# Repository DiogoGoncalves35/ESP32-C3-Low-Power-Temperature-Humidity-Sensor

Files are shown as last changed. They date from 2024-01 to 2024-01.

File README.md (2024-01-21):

# ESP32-C3-Low-Power-Temperature-Humidity-Sensor

  

This board is designed arround SHT31 sensor and ESP32-C3 microcontroller. It's a low power board, arround 6 µA during deep sleep, it's super efficient during communication, makes it perfect to be powered with a Li-Ion battery. The next image shows version 2.0.

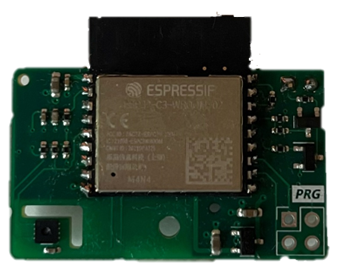
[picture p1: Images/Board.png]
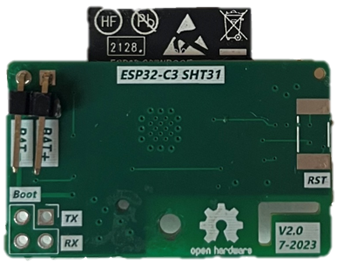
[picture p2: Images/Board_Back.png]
 

Two versions were designed, the first was a experimental board and the second the final one. The second version solved the problems found on the first and also added a circuit to control the voltage divider, this helped reduce the deep sleep current by 9 µA.

| | V1.0 | V2.0 | 
| --- | ---  | ---  |
| Current Deep Sleep (µA) | 13.33 | 6.03 | 

The microcontroller wakes every 5 minutes to do the measurement and send the data. With this value, the device can last up to 1800 days with a 550 mAh Li-Ion battery. This is a estimated  value because it's not easy to calculate the exact one, the system doesn't consume the exact ammount every cycle and the battery datasheet doesn't state the BMS drawn current. 

------------

### Communication Protocol 

In order to choose the most efficient protocol, three tests were executed between BLE, ESP-NOW and MQTT. The first test was about message delivering, each test corresponds to sending messages every 5 minutes for 24 hours (288 messages per day). 

The values on the table show the average result for 10 tests.

| | ESP-NOW | MQTT | BLE (NimBLE)  |
| ---  | ---  | ---  | ---  |
| Average (%) | 100.0 | 97.4 | 99.8 |

ESP-NOW was the only protocol to delivery every message. 

MQTT couldn't get 100% in any test, it lost about 3 to 8 messages per test, this loss could be related to the library used not support QoS 0. In case the broker didn't receive the packet 750 ms after the first send, another one was published and if after 750 ms the broker still didn't received, the board entered deep sleep. Wi-Fi connection with fixed IP.

BLE in 6 tests delivered every message and in the others lost about 2 to 4 messages, for the test NimBLE library was used, the default BLE library has many problems related to memory.

The last test is about the average current and time during execution. The values on the table show the average result for 10 measurements. The time corresponds to the moment the ESP wakes from deep sleep and goes into deep sleep.

| | ESP-NOW | MQTT | BLE (NimBLE)  |
| ---  | ---  | ---  | ---  |
| Current (mA)  | 28.76 | 69.65 | 80.57 |
| Time (ms) | 85.31 | 906.26 | 737.57 |

ESP-NOW is by far the most efficient protocol, the way it's built allows communication to be direct and fast. Since it only uses the antenna to send the message, it's possible to achive low current during execution.

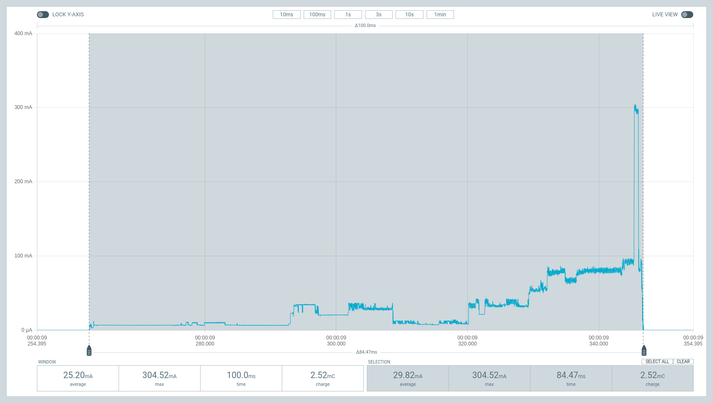
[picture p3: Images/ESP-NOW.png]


MQTT needs about 300-400 ms to connect to Wi-Fi and MQTT server, without fixed IP, connection time increases in 2 to 3 seconds. Average current increases compared to ESP-NOW because the antenna is used several times.

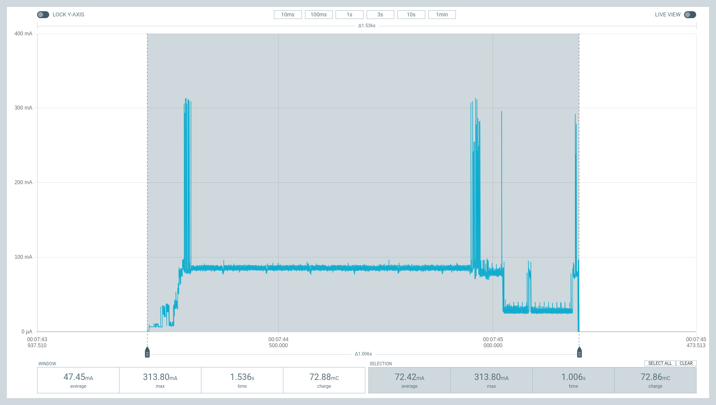
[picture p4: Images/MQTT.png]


BLE uses the antenna quite often because needs to adverstise the device, services and then transmit data to the other device. Eventhought it uses lower current, the average current is higher compared to MQTT.

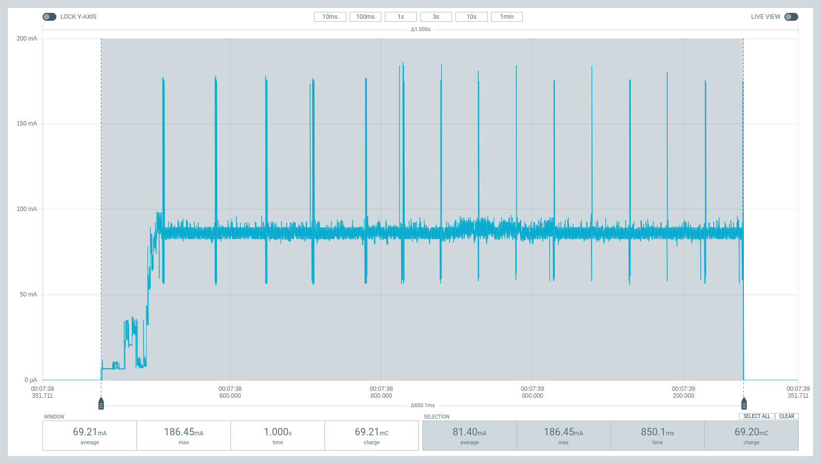
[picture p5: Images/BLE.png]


| | ESP-NOW | MQTT | BLE (NimBLE)  |
| --- | ---  | ---  | ---  |
| Difference (%) | --- | 96.10 | 95.90 |

ESP-NOW is 96.10% more efficient then MQTT and 95.90% then BLE.

After the results of both tests, ESP-NOW protocol was chose.

---

### Code 

The microcontroller saves the last reading in the RTC memory, by doing this it's possible to compare the values just measured to the ones stored in the memory. This allows the system to not send the message in case the measurements are the same and increases battery life.

```arduino
//Variables to store last measurement
RTC_DATA_ATTR double    RTC_Temperature = 0;
RTC_DATA_ATTR byte      RTC_Humidity    = 0;

// Block code after measurement
if(Data.Temperature == RTC_Temperature && Data.Humidity == RTC_Humidity)
{
    // Start deep sleep
    esp_deep_sleep_start();
}
else
{
    // Store values 
    RTC_Temperature = Data.Temperature;
    RTC_Humidity    = Data.Humidity;
}
```

The board responsible for receiving data needs to have the same data structure.

```arduino
// ESP-NOW data structure   
typedef struct struct_message 
{
  byte   ID = X;               // Board identifier
  float  Temperature;          // Temperature variable
  byte   Humidity;             // Humidity variable
  byte   Battery_Percentage;   // Battery percentage variable
} struct_message;

struct_message Data;
```

The frequency that the code runs impacts current and time of execution. The code was divide in two phases, the first is from the moment the board wakes from deep sleep to the moment it starts the ESP-NOW function, the second is from the start of ESP-NOW function to the moment it enters in deep sleep. After some measurements done, the results showed 40-160 MHz was the most efficient combination. In case the microcontroller sends every message, running with fixed 160 MHz is more efficient.

---

### Schematic 

The [schematic](/Hardware/PCB/Schematic.pdf) is arround ESP32-C3 microcontroller and SHT31 sensor. The P-Channel Mosfet BSS84 and the N-Channel Transistor S8050 control the voltage for the voltage divider. The board is designed to be powered with a Li-Ion battery that includes a BMS.

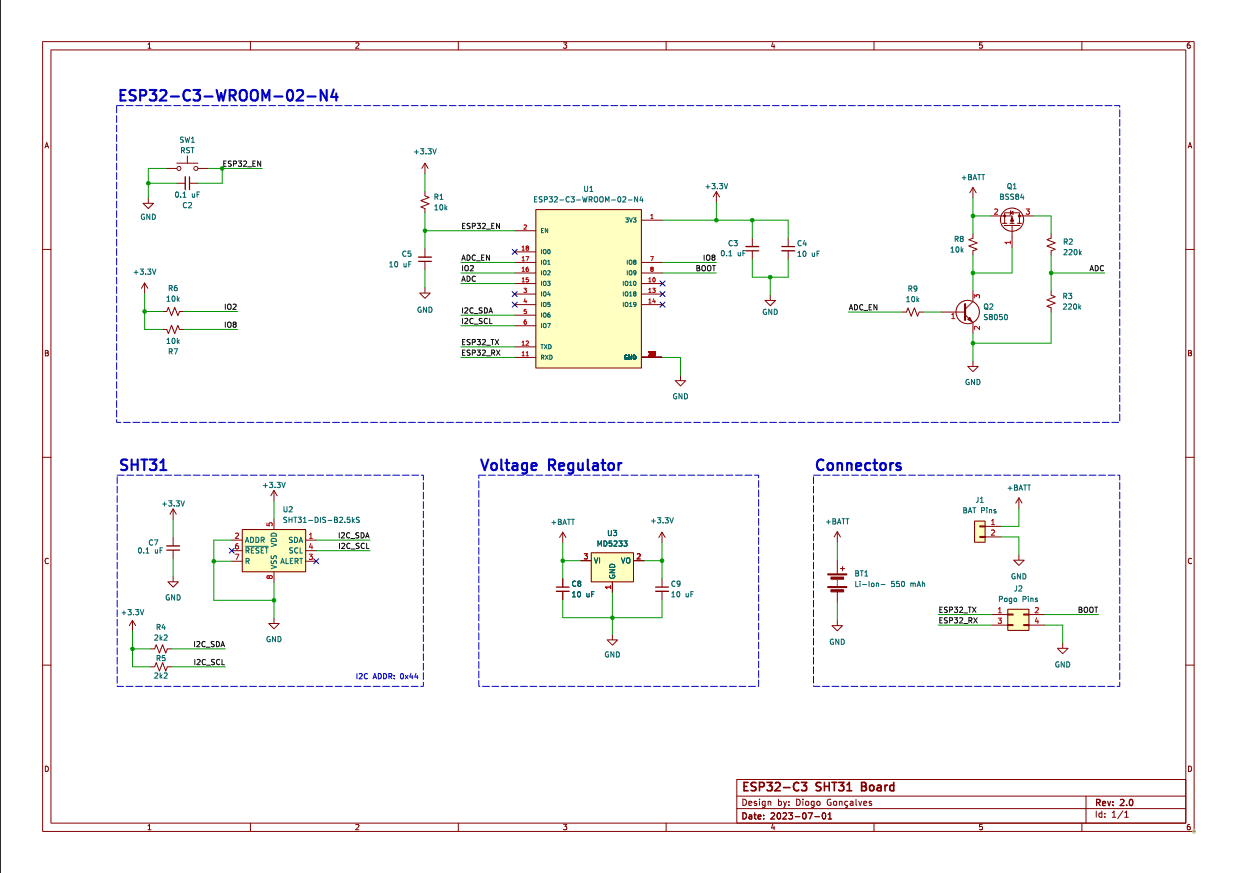
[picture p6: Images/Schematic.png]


------------

### PCB

[This](Hardware/PCB/) 1.6mm board contains 4 layers with the stackup Signal+Power/GND/GND/Signal+Power. GND area was removed closer to the sensor in order to not affect readings. The pogo pin connector is for programming the microcontroller. The reset button is located on the back.

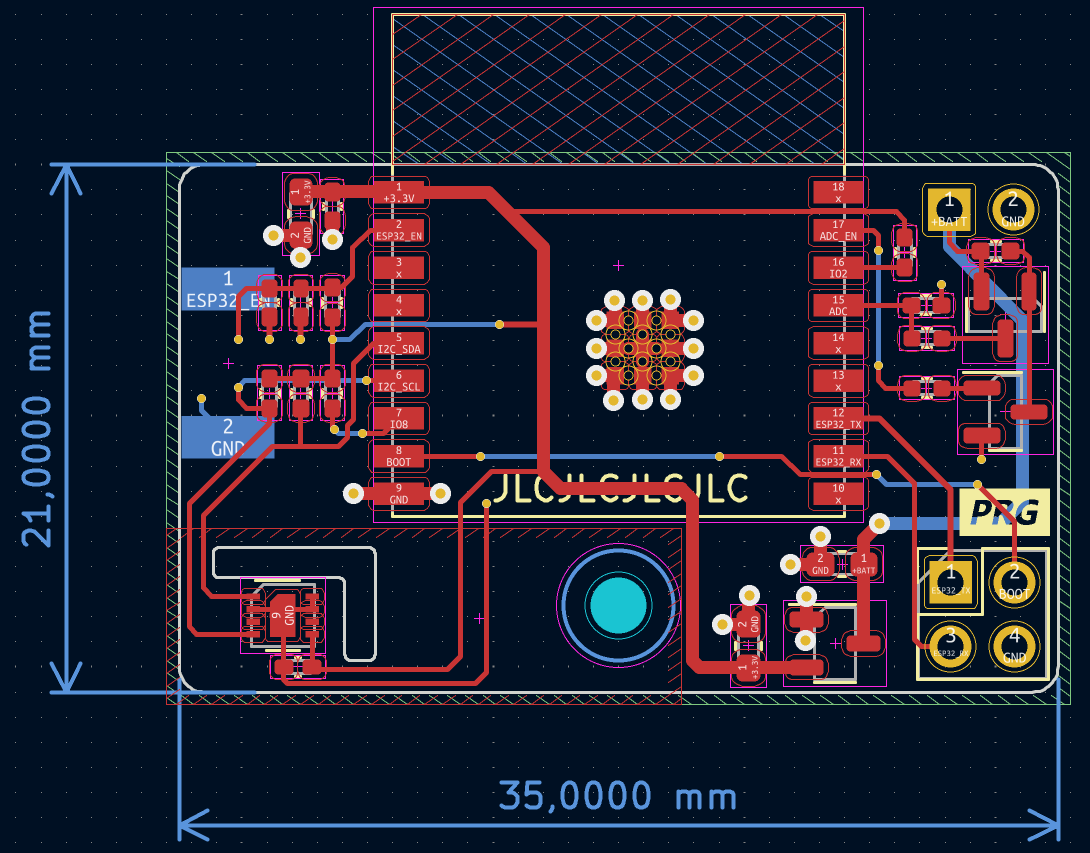
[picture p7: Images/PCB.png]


---

### Known issues

- None

------------

### To-Do

- TPL5110 Timer to control the microcontroller and reduce deep sleep current

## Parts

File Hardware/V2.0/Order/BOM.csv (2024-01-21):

Reference | Value | Footprint | LCSC | Qtd
BT1 | Li-Ion- 550 mAh | Connector_PinHeader_2.54mm:PinHeader_1x02_P2.54mm_Horizontal |  | 1
C2 | 0.1 uF | Capacitor_SMD:C_0402_1005Metric_Pad0.74x0.62mm_HandSolder | C1525 | 1
C3 | 0.1 uF | Capacitor_SMD:C_0402_1005Metric_Pad0.74x0.62mm_HandSolder | C1525 | 1
C4 | 10 uF | Capacitor_SMD:C_0603_1608Metric_Pad1.08x0.95mm_HandSolder | C19702 | 1
C5 | 10 uF | Capacitor_SMD:C_0402_1005Metric_Pad0.74x0.62mm_HandSolder | C15525 | 1
C7 | 0.1 uF | Capacitor_SMD:C_0402_1005Metric_Pad0.74x0.62mm_HandSolder | C1525 | 1
C8 | 10 uF | Capacitor_SMD:C_0603_1608Metric_Pad1.08x0.95mm_HandSolder | C19702 | 1
C9 | 10 uF | Capacitor_SMD:C_0603_1608Metric_Pad1.08x0.95mm_HandSolder | C19702 | 1
J1 | BAT Pins |  |  | 1
J2 | Pogo Pins | Connector_PinHeader_2.54mm:PinHeader_2x02_P2.54mm_Vertical |  | 1
Q1 | BSS84 | Package_TO_SOT_SMD:SOT-23 | C8492 | 1
Q2 | S8050 | Package_TO_SOT_SMD:SOT-23 | C2150 | 1
R1 | 10k | Resistor_SMD:R_0402_1005Metric_Pad0.72x0.64mm_HandSolder | C25744 | 1
R2 | 220k | Resistor_SMD:R_0402_1005Metric_Pad0.72x0.64mm_HandSolder | C25767 | 1
R3 | 220k | Resistor_SMD:R_0402_1005Metric_Pad0.72x0.64mm_HandSolder | C25767 | 1
R4 | 2k2 | Resistor_SMD:R_0402_1005Metric_Pad0.72x0.64mm_HandSolder | C25879 | 1
R5 | 2k2 | Resistor_SMD:R_0402_1005Metric_Pad0.72x0.64mm_HandSolder | C25879 | 1
R6 | 10k | Resistor_SMD:R_0402_1005Metric_Pad0.72x0.64mm_HandSolder | C25744 | 1
R7 | 10k | Resistor_SMD:R_0402_1005Metric_Pad0.72x0.64mm_HandSolder | C25744 | 1
R8 | 10k | Resistor_SMD:R_0402_1005Metric_Pad0.72x0.64mm_HandSolder | C25744 | 1
R9 | 10k | Resistor_SMD:R_0402_1005Metric_Pad0.72x0.64mm_HandSolder | C25744 | 1
SW1 | RST | SMD Switch:KEY-SMD_KSS-2G |  | 1
U1 | ESP32-C3-WROOM-02-N4 | ESP32-C3 WROOM-02:MODULE_ESP32-C3-WROOM-02-H4 | C2934560 | 1
U2 | SHT31-DIS-B2.5kS | Sensor_Humidity:Sensirion_DFN-8-1EP_2.5x2.5mm_P0.5mm_EP1.1x1.7mm | C80862 | 1
U3 | MD5233 | Package_TO_SOT_SMD:SOT-23-3 | C920353 | 1

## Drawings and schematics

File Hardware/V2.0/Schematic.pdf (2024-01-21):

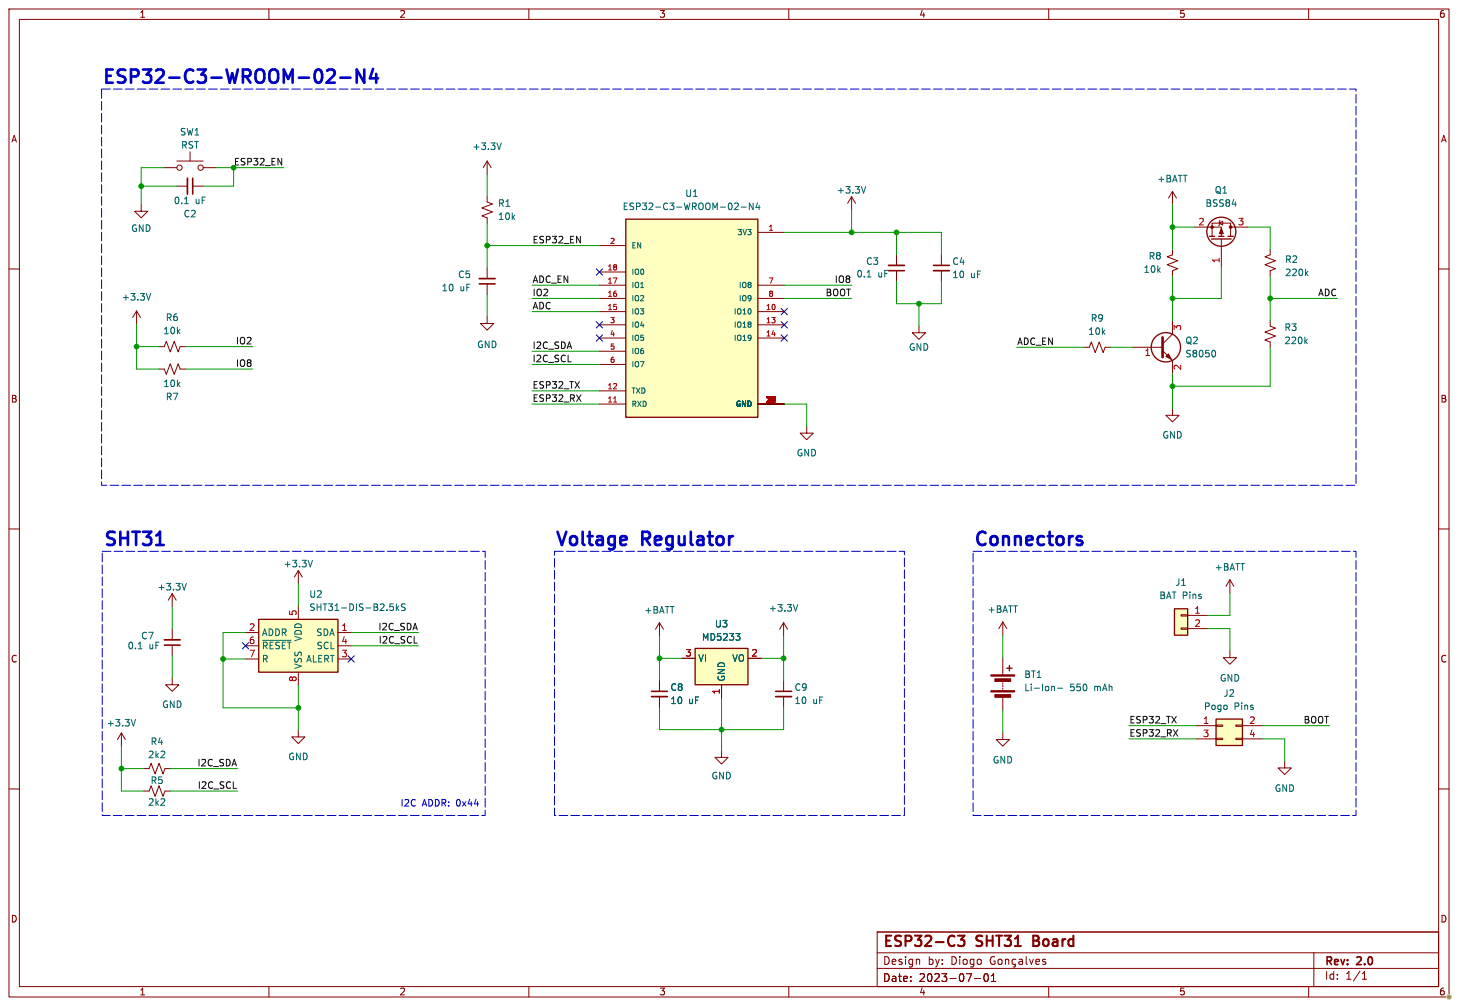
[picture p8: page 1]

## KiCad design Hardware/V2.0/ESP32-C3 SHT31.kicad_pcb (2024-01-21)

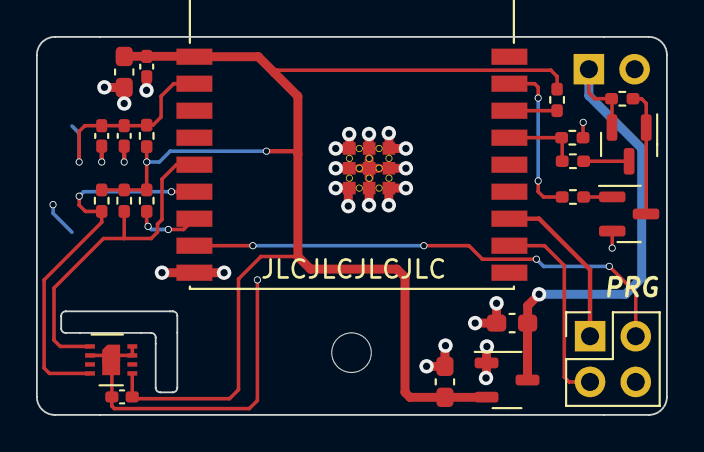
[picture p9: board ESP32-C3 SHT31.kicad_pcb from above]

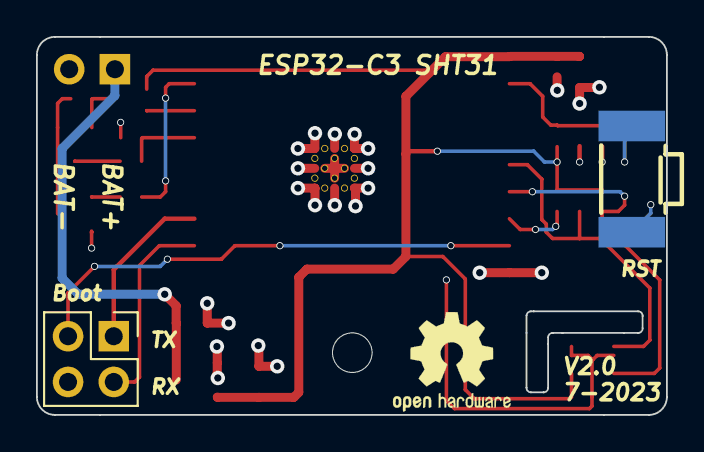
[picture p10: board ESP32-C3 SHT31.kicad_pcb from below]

Board: 4 copper layers, 35.0 x 21.0 mm, 24 parts (2 on the bottom side), 16 nets.

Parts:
BT1: Li-Ion- 550 mAh; PinHeader_1x02_P2.54mm_Horizontal
C2, C3, C7: 0.1 uF; C_0402_1005Metric_Pad0.74x0.62mm_HandSolder
C4, C8, C9: 10 uF; C_0603_1608Metric_Pad1.08x0.95mm_HandSolder
C5: 10 uF; C_0402_1005Metric_Pad0.74x0.62mm_HandSolder
J2: Pogo Pins; PinHeader_2x02_P2.54mm_Vertical
Q1: BSS84; SOT-23
Q2: S8050; SOT-23
R1, R6, R7, R8, R9: 10k; R_0402_1005Metric_Pad0.72x0.64mm_HandSolder
R2, R3: 220k; R_0402_1005Metric_Pad0.72x0.64mm_HandSolder
R4, R5: 2k2; R_0402_1005Metric_Pad0.72x0.64mm_HandSolder
SW1: RST; KEY-SMD_KSS-2G
U1: ESP32-C3-WROOM-02-N4; MODULE_ESP32-C3-WROOM-02-H4
U2: SHT31-DIS-B2.5kS; Sensirion_DFN-8-1EP_2.5x2.5mm_P0.5mm_EP1.1x1.7mm
U3: MD5233; SOT-23-3

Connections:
+3.3V: C3.2, C4.1, C7.2, C9.1, R1.1, R4.1, R5.1, R6.1, R7.1, U1.1 (3V3), U2.5 (VDD), U3.2 (VO)
+BATT: BT1.1 (+), C8.1, Q1.2 (S), R8.1, U3.3 (VI)
/ADC: R2.2, R3.2, U1.15 (IO3)
/ADC_EN: R9.1, U1.17 (IO1)
/BOOT: J2.2, U1.8 (IO9)
/ESP32_EN: C2.1, C5.2, R1.2, SW1.1, U1.2 (EN)
/ESP32_RX: J2.3, U1.11 (RXD)
/ESP32_TX: J2.1, U1.12 (TXD)
/I2C_SCL: R5.2, U1.6 (IO7), U2.4 (SCL)
/I2C_SDA: R4.2, U1.5 (IO6), U2.1 (SDA)
/IO2: R6.2, U1.16 (IO2)
/IO8: R7.2, U1.7 (IO8)
GND: BT1.2 (-), C2.2, C3.1, C4.2, C5.1, C7.1, C8.2, C9.2, J2.4, Q2.2 (E), R3.1, SW1.2, U1.9 (GND), U1.19 (GND), U1.20 (GND), U1.21 (GND), U1.22 (GND), U1.23 (GND), U1.24 (GND), U1.25 (GND), U1.26 (GND), U1.27 (GND), U1.28 (GND), U1.29 (GND), U1.30 (GND), U1.31 (GND), U1.32 (GND), U1.33 (GND), U1.34 (GND), U1.35 (GND), U1.36 (GND), U1.37 (GND), U1.38 (GND), U1.39 (GND), U2.2 (ADDR), U2.7 (R), U2.8 (VSS), U2.9 (VSS), U3.1 (GND)
unnamed: Q1.3 (D), R2.1
unnamed: Q1.1 (G), Q2.3 (C), R8.2
unnamed: Q2.1 (B), R9.2

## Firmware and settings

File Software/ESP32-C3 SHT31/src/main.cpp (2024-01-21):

// Libraries
#include <Arduino.h>
#include <Wire.h>
#include "SHT31.h"
#include <SPI.h>
#include <esp_now.h>
#include <esp_wifi.h>
#include <WiFi.h>


// Mac Address
uint8_t broadcastAddress[] = {0xXX, 0xXX, 0xXX, 0xXX, 0xXX, 0xXX};    // Hub MAC

// Deep Sleep variables
#define uS_TO_S_FACTOR 1000000ULL  // Conversion
#define TIME_TO_SLEEP  300         // Time to deep sleep

// ESP-NOW variable
esp_now_peer_info_t peerInfo;

// ESP-NOW data structure   
typedef struct struct_message 
{
  byte   ID = X;               // Board identifier
  float  Temperature;          // Temperature variable
  byte   Humidity;             // Humidity variable
  byte   Battery_Percentage;   // Battery percentage variable
} struct_message;

struct_message Data;


// Variables to store last measurement
RTC_DATA_ATTR double RTC_Temperature = 0;
RTC_DATA_ATTR byte RTC_Humidity = 0;


// Variable to verify if a message was send
bool Send = false;


// Function to communicate with SHT31 sensor
void Sensor()
{ 
  // Sensor variable
  SHT31 SHT;

  // Variable for time cicle with current millis
  unsigned long Wait_Sensor = millis();

  //Cycle that ends after 50 ms or in case there is connection with sensor
  // ^ - XOR
  while((!SHT.begin(0x44, 6, 7)) ^ (millis() >= Wait_Sensor + 50))
  {
    // Delay 
    delayMicroseconds(1);
  }
  
  // Set I2C speed to 400 KHz
  Wire.setClock(400000);

  // Read, if error, start deep sleep
  if(SHT.read())
  {
    // Measurement and conversion
    Data.Temperature  = roundf(SHT.getTemperature()*10)/10;     // Temperature with only one decimal place
    Data.Humidity     = round(SHT.getHumidity());               // Humidity as int value
  }
  else
  {
    // Start deep sleep
    esp_deep_sleep_start();
  }

  // Compare measurements
  if(Data.Temperature == RTC_Temperature && Data.Humidity == RTC_Humidity)
  {
    // Start deep sleep
    esp_deep_sleep_start();
  }
  else
  {
    // Store values 
    RTC_Temperature = Data.Temperature;
    RTC_Humidity    = Data.Humidity;
  }
}


// Function called automatically after message is sent
void OnDataSent(const uint8_t *mac_addr, esp_now_send_status_t status) 
{
  // If message is sent with sucess, start deep sleep
  if(status == ESP_NOW_SEND_SUCCESS)
  {
    // Start deep sleep
    esp_deep_sleep_start();
  }
  else
  {
    // If message was sent two times, start deep sleep
    if (Send)
    {
      // Start deep sleep
      esp_deep_sleep_start();
    }

    // Send as true
    Send = true;

    // Send one last time
    esp_now_send(broadcastAddress,(uint8_t *) &Data, sizeof(Data)); 
  }
}


// Function to read battery voltage and convert to percentage
void Battery()
{
  // IO1 as OUTPUT
  pinMode(1, OUTPUT);

  // Turn on ADC_EN
  digitalWrite(1, HIGH);
  
  //IO3 as INPUT
  pinMode(3,INPUT);  

  // Variable to store 3 measurements
  uint32_t Vbatt = 0;

  // 3 measurements
  for(int i = 0; i < 3; i++) 
  {
    // Read
    // Attenuation 11db (Default), Voltage : 0,15V - 2,45V 
    Vbatt = Vbatt + analogReadMilliVolts(3);   
  }

  // Turn off ADC_EN
  digitalWrite(1, HIGH);
  
  // Attenuation 1/2, conversion from mV to V, average readings and round to 1 decimal place
  float Vbattf = roundf((2 * (Vbatt / 3) / 1000.0)*10)/10;          

  // Conversion to percentage, max voltage 4.2V(100%), 3V(0%)
  Data.Battery_Percentage = ((Vbattf - 3.0) * (100 - 0) / (4.2 - 3) + 0);
}


// ESP-NOW function 
void ESP_NOW()
{
  // Set frequency
  setCpuFrequencyMhz(160);

  // WiFi as station mode
  WiFi.mode(WIFI_STA);

  // Start protocol, if error, start deep sleep
  if (esp_now_init() != ESP_OK)   
  {
    // Start deep sleep
    esp_deep_sleep_start();
  }
  
  // Register callback function
  esp_now_register_send_cb(OnDataSent);

  // Register peer
  memcpy(peerInfo.peer_addr, broadcastAddress, 6);
  peerInfo.channel = 1;  
  peerInfo.encrypt = false;
  
  // Add peer, if error, start deep sleep  
  if (esp_now_add_peer(&peerInfo) != ESP_OK)
  {
    // Start deep sleep
    esp_deep_sleep_start();
  }

  // Send data
  esp_now_send(broadcastAddress,(uint8_t *) &Data, sizeof(Data)); 
}


// Setup
void setup()  
{ 
  // Set frequency
  setCpuFrequencyMhz(40);

  // Ativate deep sleep timer
  esp_sleep_enable_timer_wakeup(TIME_TO_SLEEP * uS_TO_S_FACTOR);

  // SHT31 function
  Sensor();

  // Battery function
  Battery();

  // ESP-NOW function
  ESP_NOW();

  // Delete Loop
  vTaskDelete(NULL);   
}


// Loop
void loop() {}
